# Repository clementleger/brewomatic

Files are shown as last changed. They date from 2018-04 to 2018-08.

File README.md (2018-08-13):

# Disclaimer

I am not experienced with brewing so, be indulgent with what you could found in the following explanations.

# Why ?

While trying to make my own brewing system, I did not find any easy to use and well explained system for small brewing setup.
OpenArdBir code is not well architectured and does not support a full featured screen or an SD card.
I wanted a configurable system to match user needs.

#  Brew-O-Matic

Brew-O-Matic aims to be an easy to use brewing system for really (really (really)) small  all-in-one brewing setup.
It contains the following features:
* Temperature probes:
 * PT100 via MAX31865
 * DS18B20
* Input
 * Rotary Encoder
* LCD support
 * LCD2004 (Discount Controller)
 * ILI9341 (via uCglig, incomplete support)
* Pump control via MOSFET
* Heating element support
 * 50/60Hz main automatic detection
 * PID controlled heating
* Beeper
* Internationalization

Some feature can be opt out such as beeper and sd card.
Others can be choosen according to your hardware

## Design

BrewOMatic is designed to easily add a temperature sensor, input, display, etc.

## Adding a language

Languages support can easily be added. You simply have to add a Lang<YourLanguage>.h file to the lang directory.
To do that, simply recopy the LangEnglish.h file and translate the existing strings.
Be careful not to reorder entries ! (tech hint: gcc-avr does not support designated initializer)

# Building

## Configuration

In order to configure BrewOMatic to suit your configuration, you can modify Config.h
All options are clearly documented. The default configuration suit the custom brewing controller.

## Needed libraries

Depending on your configuration, you will need the following libraries:
* SD
* PIDv1
* LiquidCrystal
* TimerOne
* uCGlib
* Rotary Encoder
* TempDS18B20

## Command

Using and arduino ide, load the BrewOMatic.ino file into the IDE.
Compile it and upload it to the arduino.

# Usage

It is advised to use a SD card to store recipe easily

## Modes

### Manual mode

When in manual, mode, user can control pump, temperature

### Recipe execution

In order to execute a recipe, go Browse SD card.

## Recipe format

Recipes are stored in .br (Brew Recipe) files on SD card.
The format is basically a csv files with specific values:

Lines format is the following:
step;duration;temperature;pump_enable;pump_duty_cycle

Step is mainly an indicator to display the correct step name on LCD.
Step can be one of the following value:
 - H: Heating step
 - M: Mashing step
 - B: Boiling step
 - C: Cooling

Duration is then the step duration described in minutes.
Temperature is the target temperature for this phase in Celsius.
And finally pump_enable is a boolean describing if pump should be enabled for the
step. pump_duty_cycle is the duty cycle (0% - 100%) for the pump (done using PWM).

For instance, the following line tell the system that we are in a heating step for 10 minutes
and that the expected temperature is 70 degrees celsius:

H;10;70;1

Additionnaly to these main steps, some actions can be added using the following syntax:
A;action_type;time

Action type can be on of the following value:
 - I: Insert malt
 - R: Remove malt
 - C: Setup Cooler
 - H: Insert Hop
 - V: Verify everything !

If time is is equal -1, then, the action will be executed before the step.
The action must also be put before the step line in the recipe.

Check the recipe folder for some samples recipes !

# Hardware

A kicad pcb is available which contains support for 20A load control, pump and LCD 2004 support (such as for 3D printer).
The main components needed to control the brewing system are the following
* Arduino
* TRIAC for heater
* MOSFET for pump

The PCB is provided as an example configuration and I am not responsible of any damages you could have.

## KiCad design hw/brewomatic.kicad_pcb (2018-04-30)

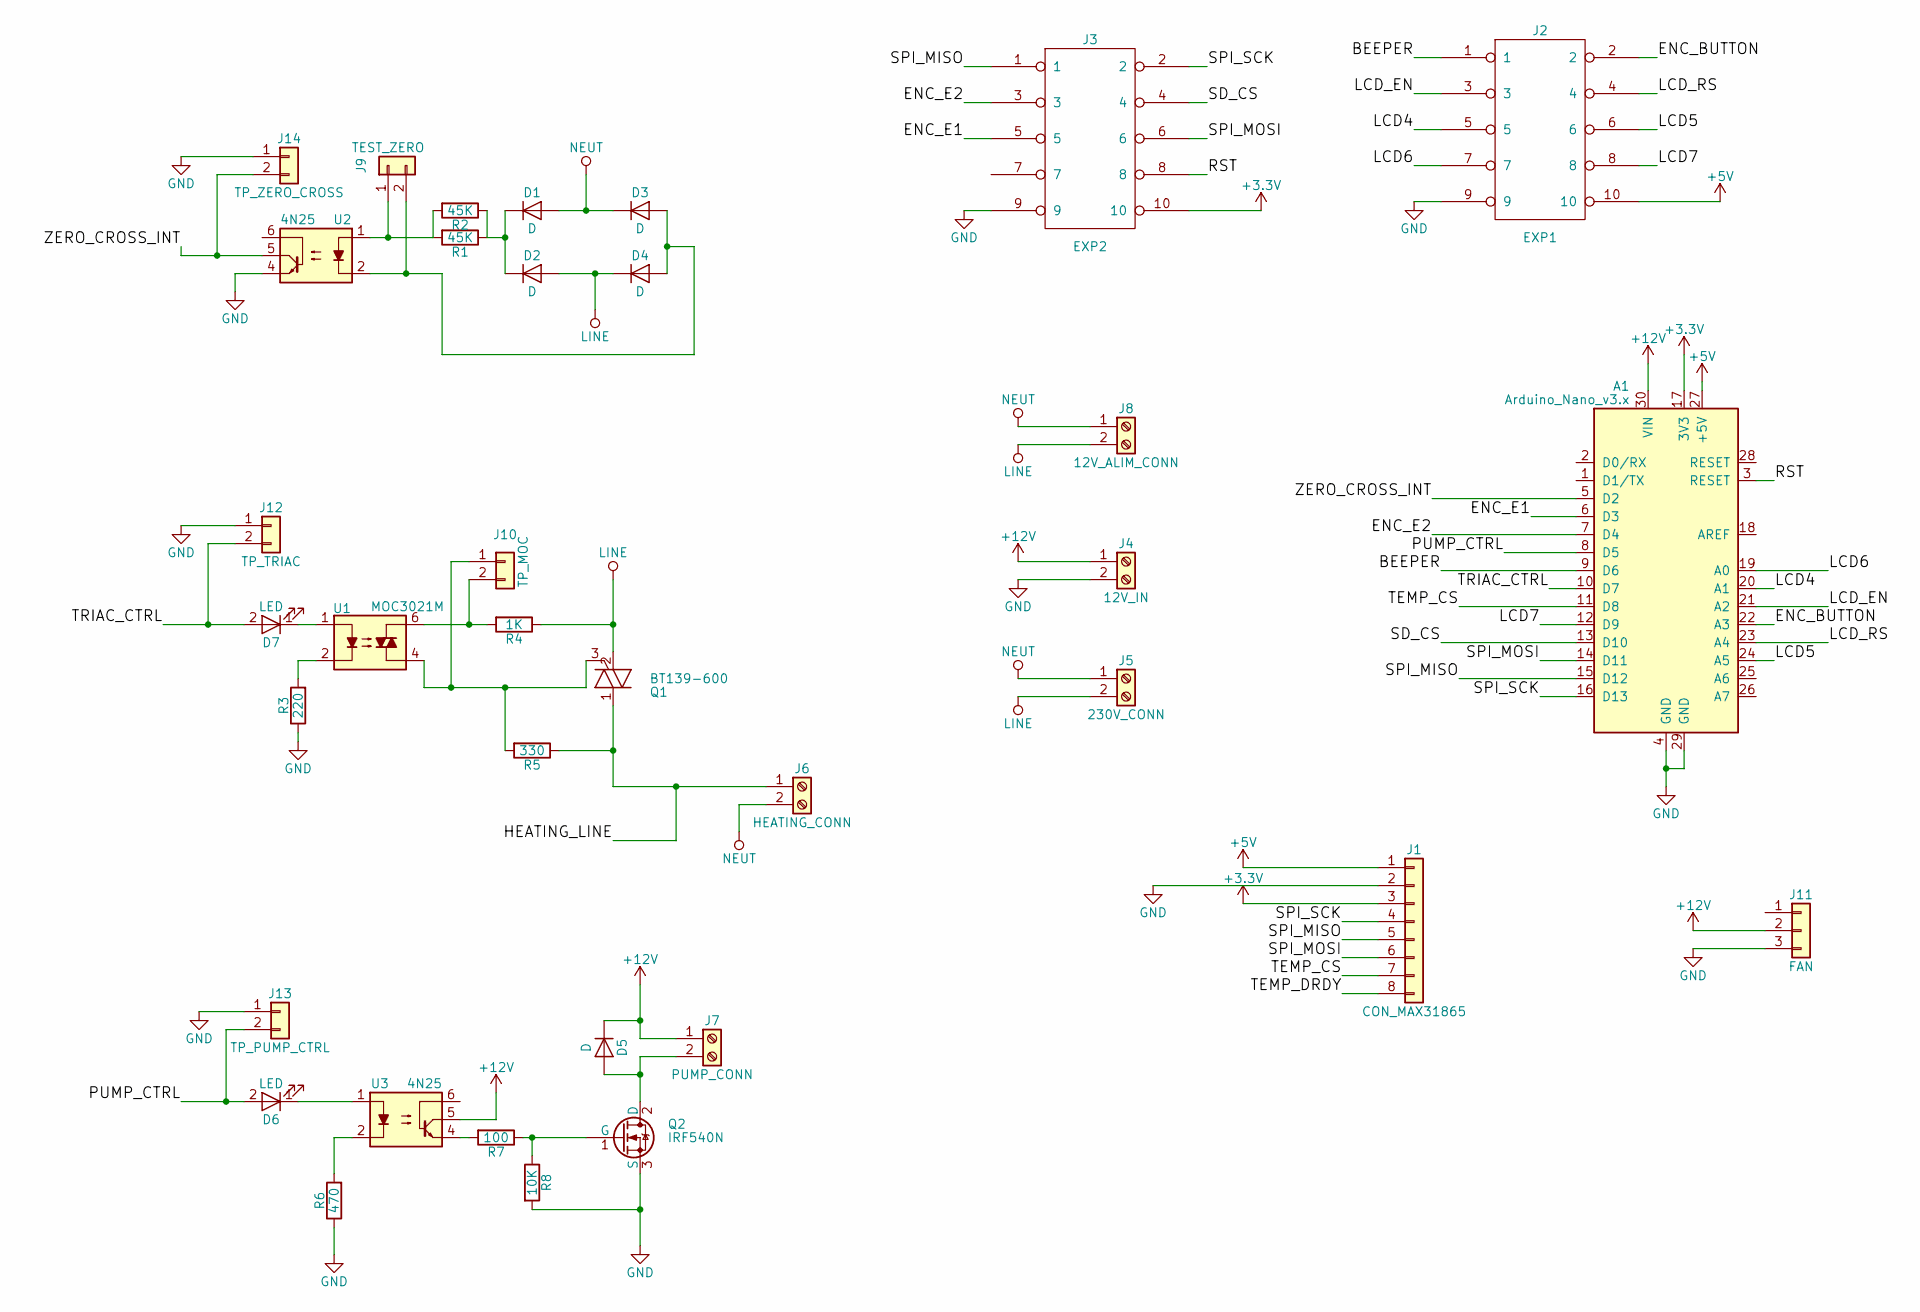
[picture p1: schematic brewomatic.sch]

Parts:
A1: Arduino_Nano_v3.x; Arduino_Nano
D1, D2, D3, D4, D5: D; D_T-1_P10.16mm_Horizontal
D6, D7: LED; LED_D5.0mm
J1: CON_MAX31865; Pin_Header_Straight_1x08_Pitch2.54mm
J2: EXP1; Pin_Header_Straight_2x05_Pitch2.54mm
J3: EXP2; Pin_Header_Straight_2x05_Pitch2.54mm
J4: 12V_IN; TerminalBlock_bornier-2_P5.08mm
J5: 230V_CONN; TerminalBlock_bornier-2_P5.08mm
J6: HEATING_CONN; TerminalBlock_bornier-2_P5.08mm
J7: PUMP_CONN; TerminalBlock_bornier-2_P5.08mm
J8: 12V_ALIM_CONN; TerminalBlock_bornier-2_P5.08mm
J9: TEST_ZERO; Pin_Header_Straight_1x02_Pitch2.54mm
J10: TP_MOC; Pin_Header_Straight_1x02_Pitch2.54mm
J11: FAN; Pin_Header_Straight_1x03_Pitch2.54mm
J12: TP_TRIAC; Pin_Header_Straight_1x02_Pitch2.54mm
J13: TP_PUMP_CTRL; Pin_Header_Straight_1x02_Pitch2.54mm
J14: TP_ZERO_CROSS; Pin_Header_Straight_1x02_Pitch2.54mm
Q1: BT139-600; TO-220_Vertical_HV
Q2: IRF540N; TO-220_Vertical
R1, R2: 45K; R_Axial_DIN0207_L6.3mm_D2.5mm_P10.16mm_Horizontal
R3: 220; R_0805_HandSoldering
R4: 1K; R_Axial_DIN0207_L6.3mm_D2.5mm_P10.16mm_Horizontal
R5: 330; R_Axial_DIN0207_L6.3mm_D2.5mm_P10.16mm_Horizontal
R6: 470; R_0805_HandSoldering
R7: 100; R_0805_HandSoldering
R8: 10K; R_0805_HandSoldering
U1: MOC3021M; DIP-6_W7.62mm_Socket
U2, U3: 4N25; DIP-6_W7.62mm_Socket

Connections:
+3V3: A1.17 (3V3), J1.3, J3.10
+5V: A1.27 (+5V), J1.1, J2.10
+12V: A1.30 (VIN), D5.1 (K), J4.1, J7.1, J11.2, U3.5
/BEEPER: A1.9 (D6), J2.1
/ENC_BUTTON: A1.22 (A3), J2.2
/ENC_E1: A1.6 (D3), J3.5
/ENC_E2: A1.7 (D4), J3.3
/HEATING_LINE: J6.1, Q1.1 (A1), R5.1
/LCD4: A1.20 (A1), J2.5
/LCD5: A1.24 (A5), J2.6
/LCD6: A1.19 (A0), J2.7
/LCD7: A1.12 (D9), J2.8
/LCD_EN: A1.21 (A2), J2.3
/LCD_RS: A1.23 (A4), J2.4
/PUMP_CTRL: A1.8 (D5), D6.2 (A), J13.2
/RST: A1.3 (RESET), J3.8
/SD_CS: A1.13 (D10), J3.4
/SPI_MISO: A1.15 (D12), J1.5, J3.1
/SPI_MOSI: A1.14 (D11), J1.6, J3.6
/SPI_SCK: A1.16 (D13), J1.4, J3.2
/TEMP_CS: A1.11 (D8), J1.7
/TEMP_DRDY: J1.8
/TRIAC_CTRL: A1.10 (D7), D7.2 (A), J12.2
/ZERO_CROSS_INT: A1.5 (D2), J14.2, U2.5
GND: A1.4 (GND), A1.29 (GND), J1.2, J2.9, J3.9, J4.2, J11.3, J12.1, J13.1, J14.1, Q2.3 (S), R3.1, R6.1, R8.2, U2.4
LINE: D2.2 (A), D4.1 (K), J5.2, J8.2, Q1.2 (A2), R4.1
NEUT: D1.2 (A), D3.1 (K), J5.1, J6.2, J8.1
unnamed: D1.1 (K), D2.1 (K), R1.1, R2.1
unnamed: D3.2 (A), D4.2 (A), J9.2, U2.2
unnamed: D5.2 (A), J7.2, Q2.2 (D)
unnamed: D6.1 (K), U3.1
unnamed: D7.1 (K), U1.1
unnamed: J9.1, R1.2, R2.2, U2.1
unnamed: J10.1, Q1.3 (G), R5.2, U1.4
unnamed: J10.2, R4.2, U1.6
unnamed: Q2.1 (G), R7.1, R8.1
unnamed: R3.2, U1.2
unnamed: R6.2, U3.2
unnamed: R7.2, U3.4

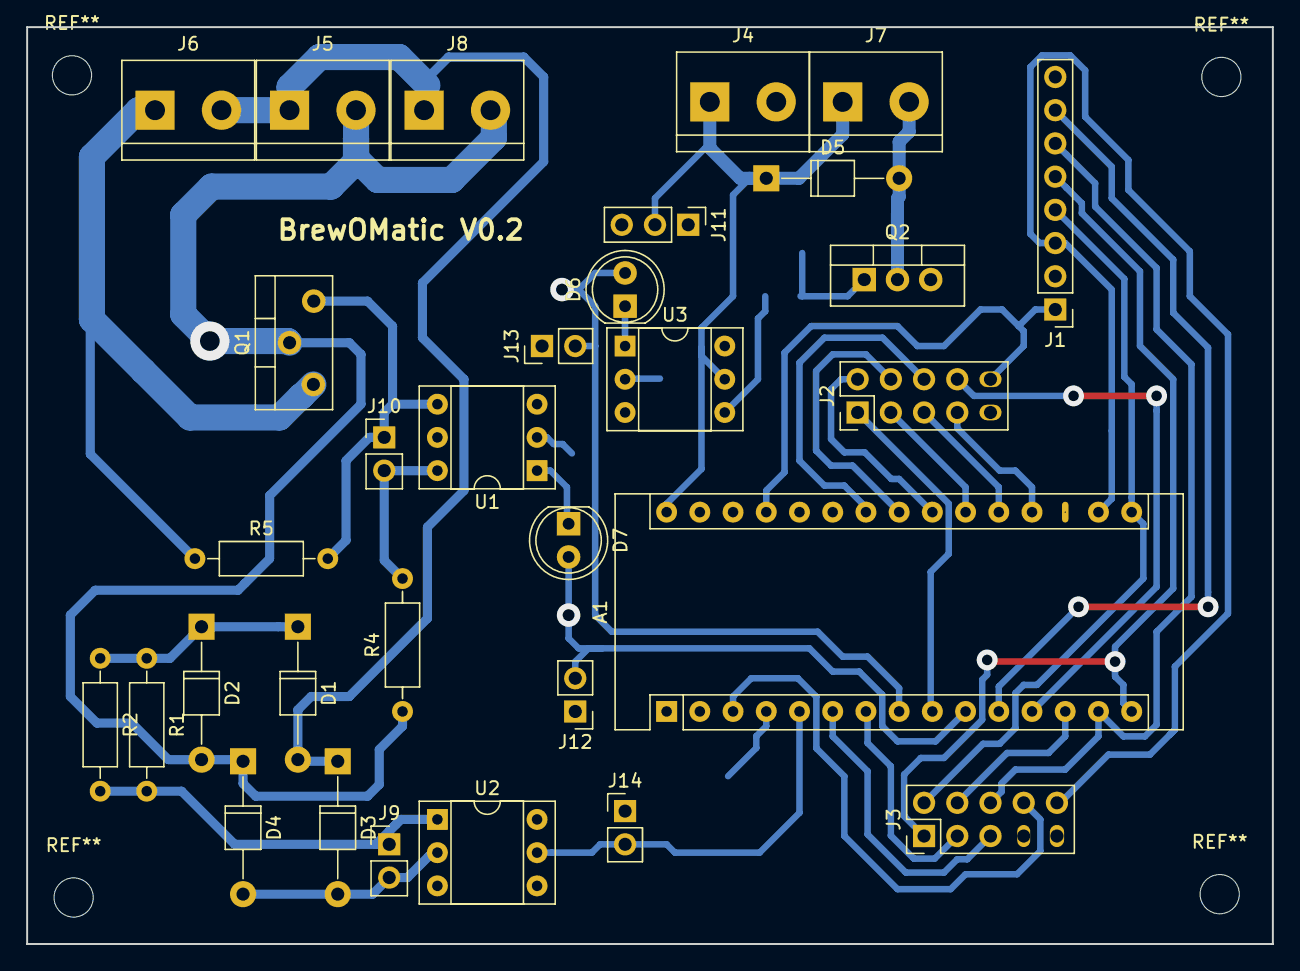
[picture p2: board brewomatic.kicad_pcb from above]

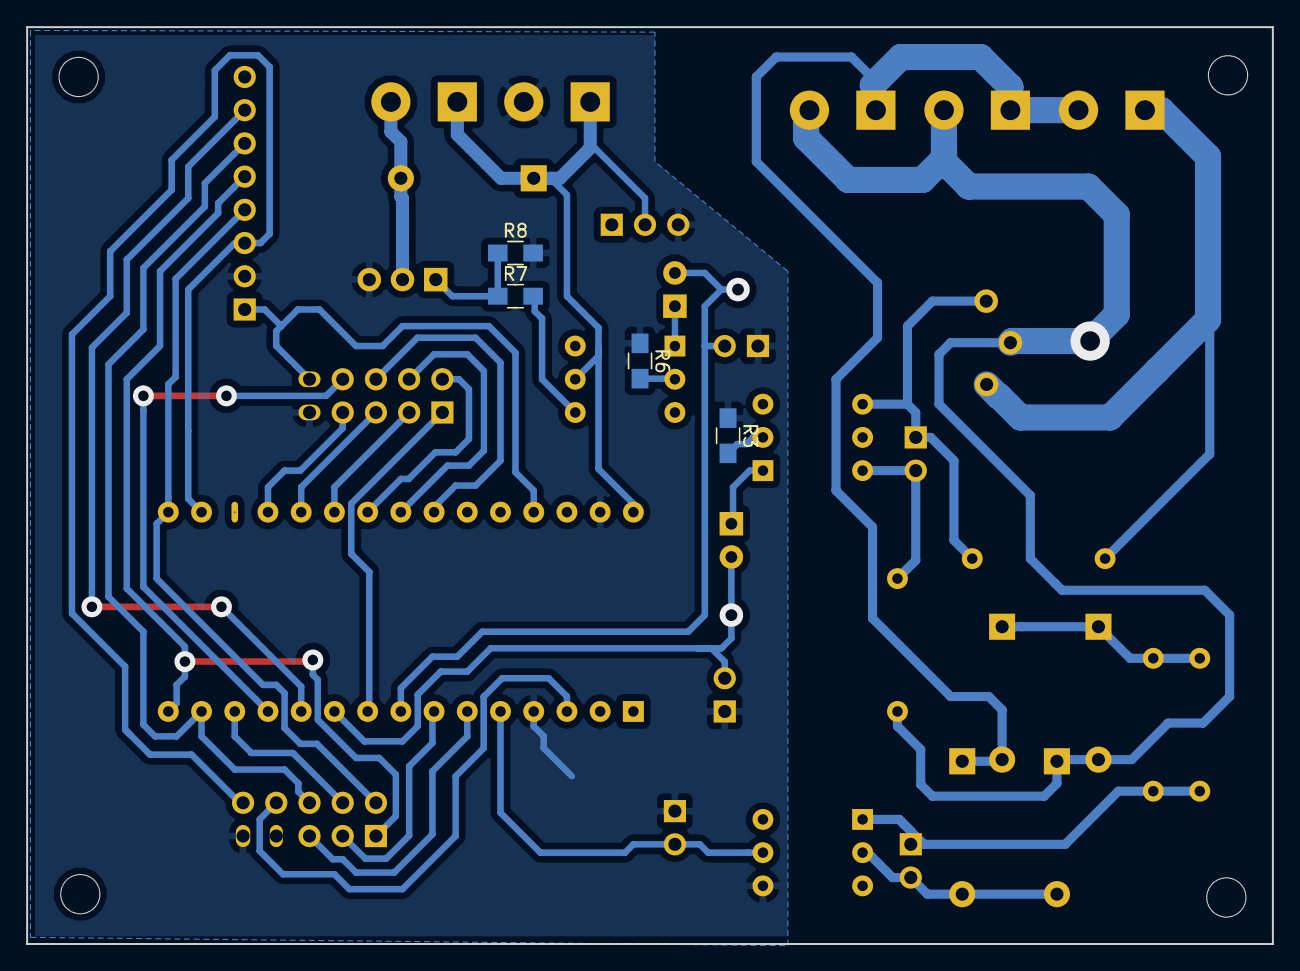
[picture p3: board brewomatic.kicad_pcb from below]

Board: 2 copper layers, 95.2 x 70.1 mm, 35 parts (4 on the bottom side), 38 nets.

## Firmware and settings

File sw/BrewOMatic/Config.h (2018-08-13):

#ifndef _BREWOMATIC_CONFIG
#define _BREWOMATIC_CONFIG

/***********************************************************************
 *                       General Settings
 **********************************************************************/
/**
 * Languages to use:
 * - English: English language
 */
#define DISP_LANGUAGE	English

/**
 * Enable beeper support
 */
#define USE_BEEPER	1

/**
 * Pin where the beeper is connected (must be a PWM one)
 */
#define BEEPER_PIN	6

/**
 * Duration of beeper click sound
 */
#define BEEPER_CLICK_DURATION	5

/**
 * Serial baudrate to use
 */
#define SERIAL_BAUDRATE 115200

/**
 * Set to 0 to disable serial output and save some bytes
 * Serial output will output informations periodically.
 */
#define DEBUG	0

/**
 * Output statistic on serial periodically if enabled
 */
#define STAT_OUTPUT 1

/**
 * Output statistic periodically
 * if defined, statistics will be printed eriodically on serial
 */
#define STAT_OUTPUT_INTERVAL	1000

/**
 * Define to output statistics on serial
 */
#define STAT_OUTPUT_SERIAL	1

/**
 * Define to output statistics on sd card
 * SD card must be enabled for that obviously
 */
#define STAT_OUTPUT_SD	1

/**
 * Delay before starting in seconds
 */
#define START_DELAY	0

/***********************************************************************
 *                       SD Card
 **********************************************************************/

#define USE_SD_CARD	1

/**
 * SD Card chip select
 */
#define SD_CARD_CHIP_SELECT	10

/**
 * Maximum number of recipes to display on the screen
 * Adjust that according to the size of your RAM !
 */
#define MAX_DISPLAY_RECIPES	10

/***********************************************************************
 *                       Inputs
 **********************************************************************/

/**
 * Enable rotary encoder support
 */
#define ENABLE_ROTARY_ENCODER	1

/**
 * Pin where the beeper is connected
 */
#define ROTARY_ENCODER_PIN_A		3
#define ROTARY_ENCODER_PIN_B		4
#define ROTARY_ENCODER_SWITCH_PIN	A3

/**
 * Reverse encoder rotation direction
 */
#define ROTARY_ENCODER_DIR_REVERSE	1

/***********************************************************************
 *                       Display Control
 **********************************************************************/

/**
 * Uncomment to use Liquid Crystal display
 */
#define LIQUID_CRYSTAL_DISPLAY

/**
 * Liquid crystal screen configuration
 */
#define LIQUID_CRYSTAL_WIDTH	20
#define LIQUID_CRYSTAL_HEIGHT	4

#define LIQUID_CRYSTAL_RS	A4
#define LIQUID_CRYSTAL_EN	A2
#define LIQUID_CRYSTAL_D4	A1
#define LIQUID_CRYSTAL_D5	A5
#define LIQUID_CRYSTAL_D6	A0
#define LIQUID_CRYSTAL_D7	9

/**
 * Set to 1 if you want animated icons
 * Disabling it saves some space
 */
#define LIQUID_CRYSTAL_ANIM	0

/**
 * Uncomment to use ucglib display (not ready)
 */
//#define UCGLIB_DISPLAY

/**
 * Ucglib screen configuration
 */
#define UCGLIB_DISPLAY_TYPE	Ucglib_ILI9341_18x240x320_HWSPI

#define UCGLIB_CD_PIN	A1
#define UCGLIB_CS_PIN	A2
#define UCGLIB_RST_PIN	A3

/***********************************************************************
 *                       Temperature Control
 **********************************************************************/
/**
 * Uncomment to use PT100 temperature probe behind max 31865
 */
#define TEMP_MAX31865

/**
 * When using TempMax31865 probe type, the hardware SPI bus is used.
 * However, the chip select can be configured here
 */
#define MAX31865_CS_PIN		8

/**
 * Number of wire your PT100 probe is using
 * This define can be:
 * - MAX31865_2WIRE: Use 2 wires
 * - MAX31865_3WIRE: Use 3 wires
 * - MAX31865_4WIRE: Use 4 wires
 */
#define MAX31865_WIRE_COUNT	MAX31865_3WIRE

/**
 * Uncomment to use DS18B20 temperature probe
 */
//#define TEMP_DS18B20

/**
 * When using TempDS18B20 probe type, we use 1wire
 * The define which pin is used for the 1wire bus
 */
#define DS18B20_ONEWIRE_PIN	4

/***********************************************************************
 *                       Heater Control
 **********************************************************************/
/**
 * PID values
 * We are talking about blackmagic here !
 */

#define PID_P_VALUE	2
#define PID_I_VALUE	5
#define PID_D_VALUE	1

/**
 * Temperature and heating control delay
 */
#define TEMP_SAMPLE_TIME_MS	500

/**
 * If using a system which requires crossing detection
 * Set this pin to an interruptible one
 */
#define ZERO_CROSSING_DETECT_PIN	2

/**
 * Heater control type, can be
 * TRIAC_CONTROL: When using a TRIAC to control AC.
 */
#define HEATER_CONTROL_TYPE		TRIAC_CONTROL

/**
 * When using a triac, set the pin number to the one asign to the
 * controlling pin
 */
#define TRIAC_CONTROL_PIN		7

/***********************************************************************
 *                       Pump Control
 **********************************************************************/
/**
 * Pump control pin
 */
#define PUMP_CONTROL_PIN	5
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

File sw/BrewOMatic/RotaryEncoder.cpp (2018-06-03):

#include "Config.h"
#include "RotaryEncoder.h"

RotaryEncoder::RotaryEncoder():
encoder(ROTARY_ENCODER_PIN_A, ROTARY_ENCODER_PIN_B)
{
	 pinMode(ROTARY_ENCODER_SWITCH_PIN, INPUT_PULLUP);
	 oldPosition = 0;
}

char RotaryEncoder::getButtonPressed()
{
	char button = BUTTON_NONE;

	if (!digitalRead(ROTARY_ENCODER_SWITCH_PIN)) {
		button = BUTTON_OK;
	} else {
		long newPosition = encoder.read();
		if (newPosition % 4)
			return BUTTON_NONE;

		if (newPosition < oldPosition)
			button = ROTARY_ENCODER_DIR_REVERSE ? BUTTON_PREV : BUTTON_NEXT;
		else if (newPosition > oldPosition)
			button = ROTARY_ENCODER_DIR_REVERSE ? BUTTON_NEXT : BUTTON_PREV;
 
		oldPosition = newPosition;
	}

	if (button)
		delay(150);

	return button;
}

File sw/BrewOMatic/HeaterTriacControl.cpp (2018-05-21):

#include "HeaterTriacControl.h"
#include "ACZeroCrossing.h"
#include "SerialOutput.h"
#include "Arduino.h"
#include "Config.h"

#include <TimerOne.h>

#define TRIAC_GATE_KEEP_TIME_US	300

#define TIMER_PERIOD		100

/**
 * Control the triac gate by using a simple 
 */

uint8_t ticks = 0;
uint8_t startTriacTicks = 0;
uint8_t stopTriacTicks = 0;

static void timerIt()
{
	ticks++;
	if (ticks == startTriacTicks) {
		/* Disable TRIAC gate */
		digitalWrite(TRIAC_CONTROL_PIN, HIGH);
	}

	if (ticks == stopTriacTicks) {
		digitalWrite(TRIAC_CONTROL_PIN, LOW);
		Timer1.stop();
	}
}

static void startTimer(uint8_t startTick, uint8_t stopTick)
{
	/* Reset ticks */
	ticks = 0;

	/* First tick will trigger right after timer setup,
	 * add 1 tick to each counter for correct time */
	startTriacTicks = startTick + 1;
	stopTriacTicks = stopTick + 1;

	/* Start Timer */
	TCNT1 = 0;
	Timer1.resume();
}

void setTimerDutyCycle(void *data)
{
	HeaterTriacControl *tc = (HeaterTriacControl *) data;

	/* When using a really low duty cycle (1)
	 * the end of previous timer could probably not have been reached.
	 * Hence, stop it right now */
	digitalWrite(TRIAC_CONTROL_PIN, LOW);

	/* Nothing to do, just return */
	if (tc->mDutyCycle == 0)
		return;

	startTimer(tc->mTriacEnableTick, tc->mTriacEnableTick + tc->mTriacGateKeepTick);
}

HeaterTriacControl::HeaterTriacControl()
{
	unsigned long ACPeriodUs;
	unsigned long tickDuration;

	pinMode(TRIAC_CONTROL_PIN, OUTPUT);
	digitalWrite(TRIAC_CONTROL_PIN, LOW);

	ACZeroCrossing::Instance().setup();

	ACPeriodUs = ACZeroCrossing::Instance().getAcPeriodUs();
	if (ACPeriodUs == 0)
		return;

	tickDuration = ACPeriodUs / 2;

	/* Since the triac takes some time to trigger,
	 * we can't make all possible combination of variation
	 * Morover, add 10 since we can have some delay while executing */ 
	tickDuration -= (TRIAC_GATE_KEEP_TIME_US);
	tickDuration /= 100;

	mDutyCycle = 0;

	mTriacGateKeepTick = TRIAC_GATE_KEEP_TIME_US / tickDuration;

	Timer1.initialize(tickDuration);
	Timer1.attachInterrupt(timerIt);
	Timer1.stop();
}

void HeaterTriacControl::enable(bool enable)
{
	if (enable) {		
		ACZeroCrossing::Instance().setCallback(setTimerDutyCycle, this);
	} else {
		ACZeroCrossing::Instance().removeCallback();
	}
}

void HeaterTriacControl::setDutyCycle(unsigned char value)
{
	noInterrupts();
	mDutyCycle = value;
	mTriacEnableTick = 100 - value;
	interrupts();
}

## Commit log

2018-03-18 Various fixes of all kind.. can't even find a correct commit message
    [Config.h]
2018-03-20 Try to reduce size and fix language
    [Config.h]
2018-03-25 Add hardware schematic
    [brewomatic.kicad_pcb, brewomatic.sch]
2018-03-25 Handle menu correctly + idle and brewing.
    [Config.h]
2018-03-25 Start layout of pcb
    [brewomatic.kicad_pcb, brewomatic.sch]
2018-03-25 WAit fopr target temperature display
2018-03-26 PCB routing done
    [brewomatic.sch]
2018-03-27 Less dangerous schematic !
    [brewomatic.kicad_pcb, brewomatic.sch]
2018-03-28 PCB: finalize layout
    [brewomatic.kicad_pcb, brewomatic.sch]
2018-03-30 PCB: fix missing TEMP_CS pin and delete sd_detect
    [brewomatic.kicad_pcb, brewomatic.sch]
2018-04-03 HW: fix schematic for zero crossing input
    [brewomatic.kicad_pcb, brewomatic.sch]
2018-04-04 PCB: update and fix LCD7/LCD5 swap
    [brewomatic.kicad_pcb, brewomatic.sch]
2018-04-05 Fix wrong pcb connection pcb
    [brewomatic.kicad_pcb, brewomatic.sch]
2018-04-08 Reverse triac terminal since it only works in one direction and fix various problems
    [brewomatic.kicad_pcb, brewomatic.sch]
2018-04-09 Add 12V fan plug
    [brewomatic.kicad_pcb, brewomatic.sch]
2018-04-11 Fix display heater, and use PSM to drive AC
    [Config.h, HeaterTriacControl.cpp]
2018-04-19 Update recipe for testing and enable temperature sensor.
2018-04-22 Fix various problems
    Fix menu update
    Use autoconvert for max31865
    Display PID output value on screen
    Fix stop brewing
    [RotaryEncoder.cpp]
2018-04-23 Better handling of enable pump and heater
2018-04-24 Fix heating control by computing pulse to trigger and not pulse to skip
    [HeaterTriacControl.cpp]
2018-04-24 Various fixes
    - Disable heater in manual mode
    - Remove useless entry from idle menu
    - Remove dbgOutput from Zero Crossing interrupt
    - Remove start delay
    [Config.h]
2018-04-25 Rework ACZeroCrossing and HeaterControl
    [HeaterTriacControl.cpp]
2018-04-27 Try to trigger triac interrupt on time...
2018-04-27 HW: Add testpoints on schematic
    [brewomatic.sch]
2018-04-30 Heating: better handling of PWM for AC
2018-04-30 hw: Add testpoints for various input/output
    This is helpful to plug logic analyzer on them
    [brewomatic.kicad_pcb, brewomatic.sch]
2018-05-13 Remove useless heating enabled option in recipe
2018-05-15 Rework config for temp and display
    [Config.h]
2018-05-21 HeaterControl: fix wrong init values
2018-05-21 DO not use special case for 100% value and protect atomic update of values
2018-05-25 Handling a maximlum fixed size of recipes to avoid stack overflow
    [Config.h]
2018-06-06 Stat: Add stratistic output for temperature
    Add sd card logging and serial output stats.
2018-06-07 Fix heater stopped at end of step
2018-08-13 Handle pump duty cycle in recipes
2018-08-13 Add sample log to creat gnuplot script
2018-08-14 Fix pumpset + display of dump
2018-08-15 Fix pump not being stopped when disabled
2018-08-15 Remove seconds from total time to display pump power correctly
2018-08-15 Fix temperature wrongly displayed on idle menu
2018-09-15 Fix wrong target temp (using currentSTepo target instead of BrewOmatic
